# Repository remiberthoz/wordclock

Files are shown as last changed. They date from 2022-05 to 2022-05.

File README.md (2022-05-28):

# Wordclock

This repository contains source code and CAD files to build and program a
wordclock.

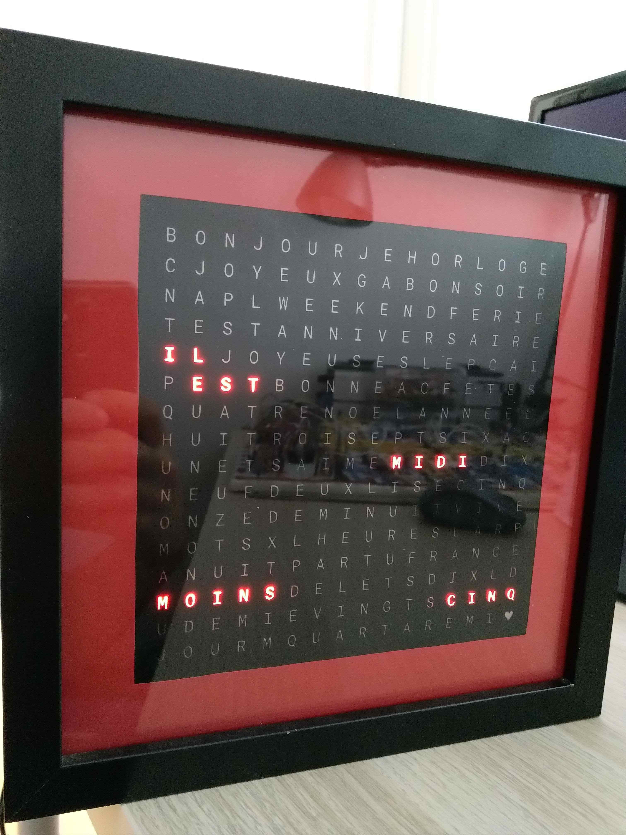
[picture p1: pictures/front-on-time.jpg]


The wordclock is designed inside an IKEA frame (SANNAHED, 25x25 cm). Behind the
front glass panel, a black mask allows light through transparent letters which
are individually backlighted with colour LEDs.

The clock displayed in the picture above spells out the time in French
(*il est midi moins cinq: it is five to noon*), but
design can easily be adapted to other languages. In addition to time of the day,
extra text for special days (*i.e.* birthdays) is highlighted in other colours.
Letters can be used as pixels to display other forms of text. The picture below
displays today's date (*Lun 18 04*: Monday *Lundi* the 18th of April).

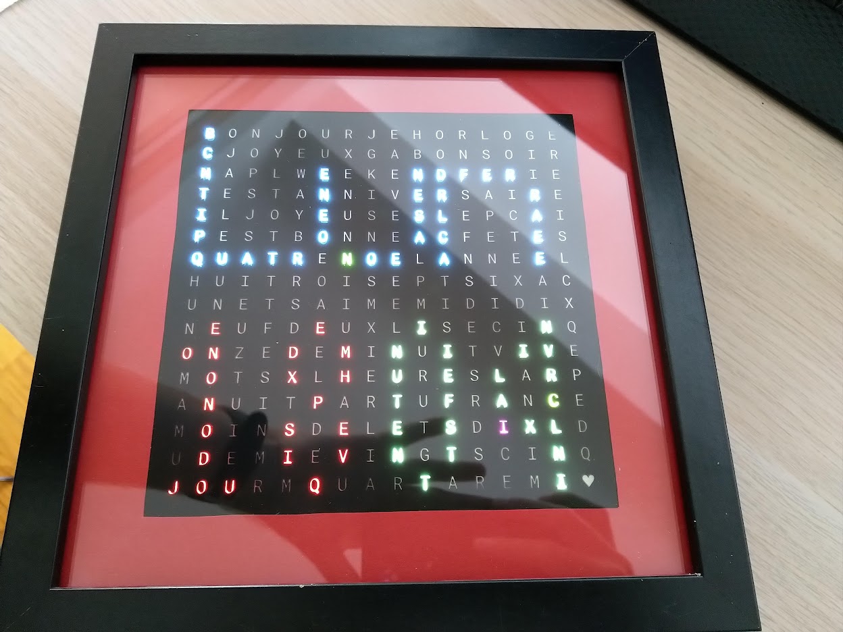
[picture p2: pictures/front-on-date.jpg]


Lights are controlled via custom printed circuit boards, multichannel LED driver
integrated circuits, and an Arduino Nano Every board breaking out a AVR XMEGA
4809 microcontroller. Timekeeping is performed with an accurate Real Time Clock
(RTC, DS3231M). The clock is powered via 5V/4A on a barrel jack, and the RTC is
internaly powered from a coin cell to ensure timekeeping even when the clock is
unplugged.

The source code attempts to follow SOLID principles. It should be easy to update
by anyone willing to add features, modify the word layout, alter colours, add
animations, and so on. As examples, the git repository includes extra behaviours
for the clock:

- it can display time with numbers, using letters as pixels
  ([source](src/Behaviour/TimeInNumbers/)),
- similarly, it can display the date ([source](src/Behaviour/DateInNumbers/)),
- on startup, it shows a splash screen with a welcome message
  ([source](src/Behaviour/HelloMessage/)),
- to debug electrical connecticity and software mappings, LEDs can be controlled
to blink one at a time ([source](src/Behaviour/BlinkOneAtATime/)),

All behaviours can be loaded on the clock, one can then use physical buttons at
the back of the frame to switch between behaviours. These buttons also permit to
adjust the time and date.

# LICENSE

Unless otherwise mentioned, the source code is licensed by Rémi Berthoz under
the [MIT License](LICENSE.txt). Exceptions are:

- The OneButton library (in `src/Protocols/OneButtons`) used to control the
  hardware push-buttons, which is licensed by Matthias Hertel under a BSD style
  license (http://www.mathertel.de/License.aspx).

- The USB USART library (in `src/Protocols/USB_USART`), adapted from
  [ArduinoCore-megaavr](https://github.com/arduino/ArduinoCore-megaavr), which
  is licensed by Arduino SA. under the terms of the GNU Lesser General Public
  License.

- The `src/millis.cpp` file, adapted from
  [ArduinoCore-megaavr](https://github.com/arduino/ArduinoCore-megaavr), which
  is licensed by Arduino SA. under the terms of the GNU Lesser General Public
  License.

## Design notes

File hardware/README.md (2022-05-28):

# KiCAD files for the project.

Contains both PCBs and mounting parts. PCBs ordered from JLCPCB, mounting parts
laser-cut ordered from Sculpteo.

* `led-matrix-pcbs` (pictures: [front with LEDs](../pictures/pcb-led-matrix-front-leds-soldered.jpg), [front without LEDs](../pictures/pcb-led-matrix-front.jpg), [back](../pictures/pcb-led-matrix-back.jpg)):
  * Main PCB, hosting the LEDs and the LED drivers. Each PCB contains 12 RGB
  LEDs in a 3x4 grid (36 LEDs total).
  * With 24 PCBs aranged in a 6x4 grid, one can get a 16x16 grid of RGB LEDs.
  * Each LED on a PCB is controlled via the onboard driver. The driver is
  controlled by a I2C interface, for which pinout is available on the PCB. The
  I2C address of the driver can be adjusted via the ADR pin (see driver
  datasheet).
* `led-matrix-bridge-pcbs` ([picture](../pictures/pcb-bridge-back.jpg)):
  * Connector PCB to join the `led-matrix-pcbs`. Each connector PCB can connect
  4 `led-matrix-pcbs` on a row.
  * This highly simplifies the I2C connections, the ADR configuration, and
  power delivery.
  * Connection between `led-matrix-pcbs` and `led-matrix-bridge-pcbs` is easy
  with pin headers.
  * With 6 PCBs, one can connect 6 rows of 4 `led-matrix-pcbs` to reach 256 RGD
  LEDs.
  * `led-matrix-bridge-pcbs` are easily connected to each other for power
  and for the SCL line of the I2C protocol. Pinout is available for the SDA line
  of the I2C protocol.
* `spacers-laser-cut`:
  * Design for laser-cut plates that hold the PCBs while letting the light of
  the LEDs through.

The main controller (that gives instructions to the LED drivers) is an Arduino
Nano Every. Timekeeping is performed by a DS3231M (breakout board from DFRobot).

## Bill of Materials

### Mounting parts

Laser-cut plates (Scultpeo):
  * 1x backplate-decor, MDF 3mm
  * 1x spacer-mount-leds, Ondulated cardboard 2.8mm
  * 1x spacer-mount-leds, Standard MDF 3mm
  * 2x spacer-nomount-leds-solderjoints, Grey compact cardboard 1mm

Screws (vis-express):
  * Screw M1.6X16 inox
  * Bolt M1.6 inox
  * Washer M2 nylon

### PCBs

PCBs (JLCPCB):
  * 24x led-matrix-pcbs, FR4 1.6mm

  | Matrix front (with LEDs) | Matrix front (without LEDs) | Matrix back |
  |:-----------------:|:--------------------:|:----:|
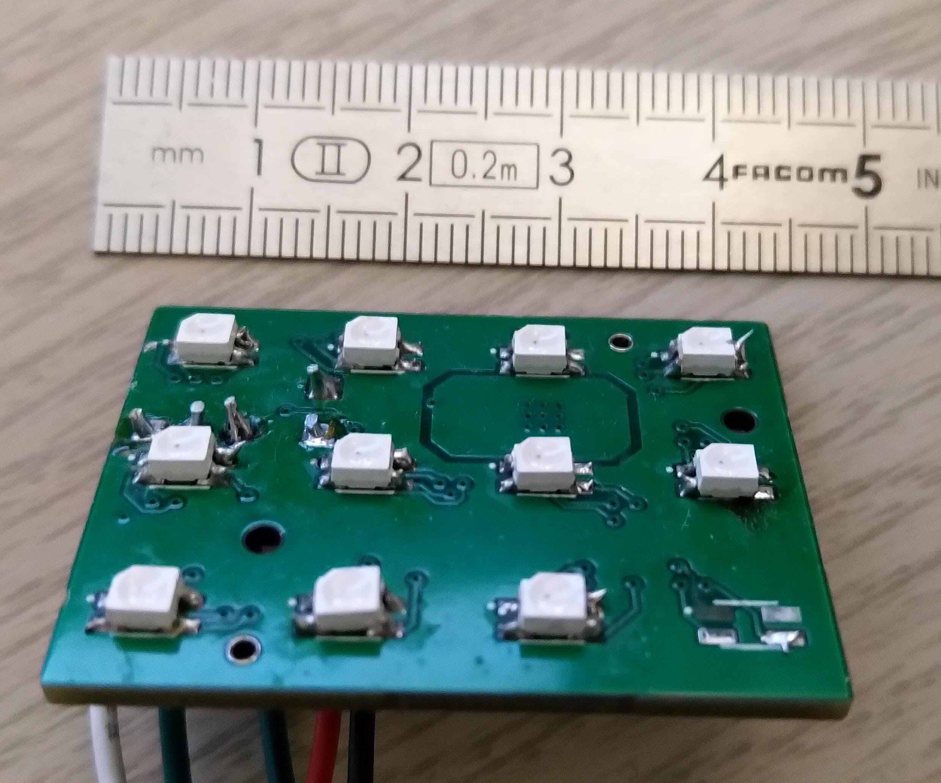
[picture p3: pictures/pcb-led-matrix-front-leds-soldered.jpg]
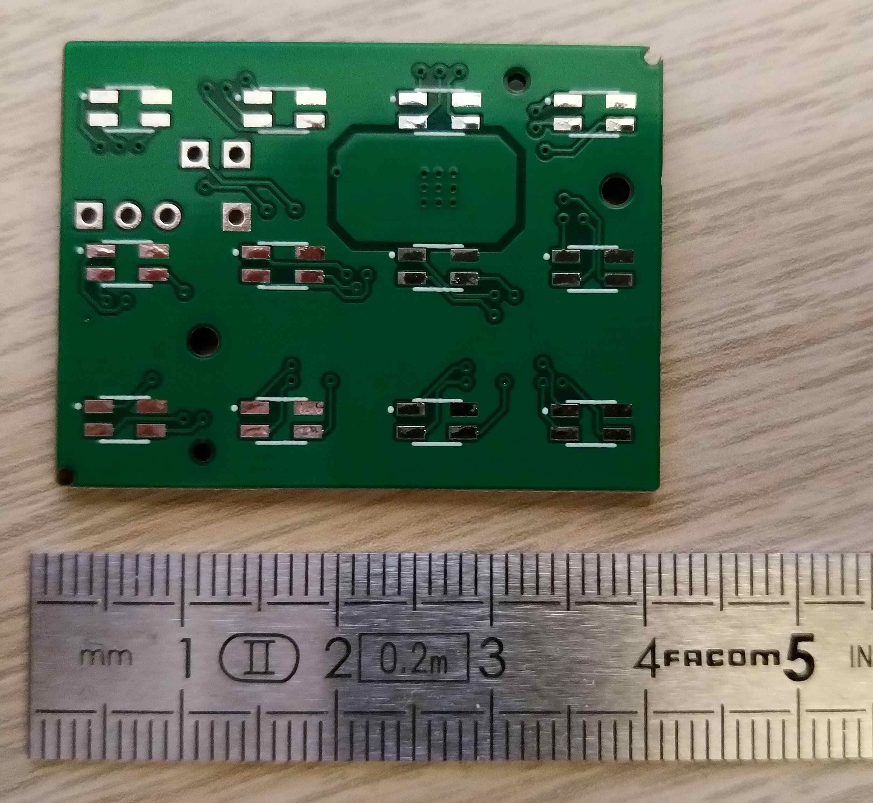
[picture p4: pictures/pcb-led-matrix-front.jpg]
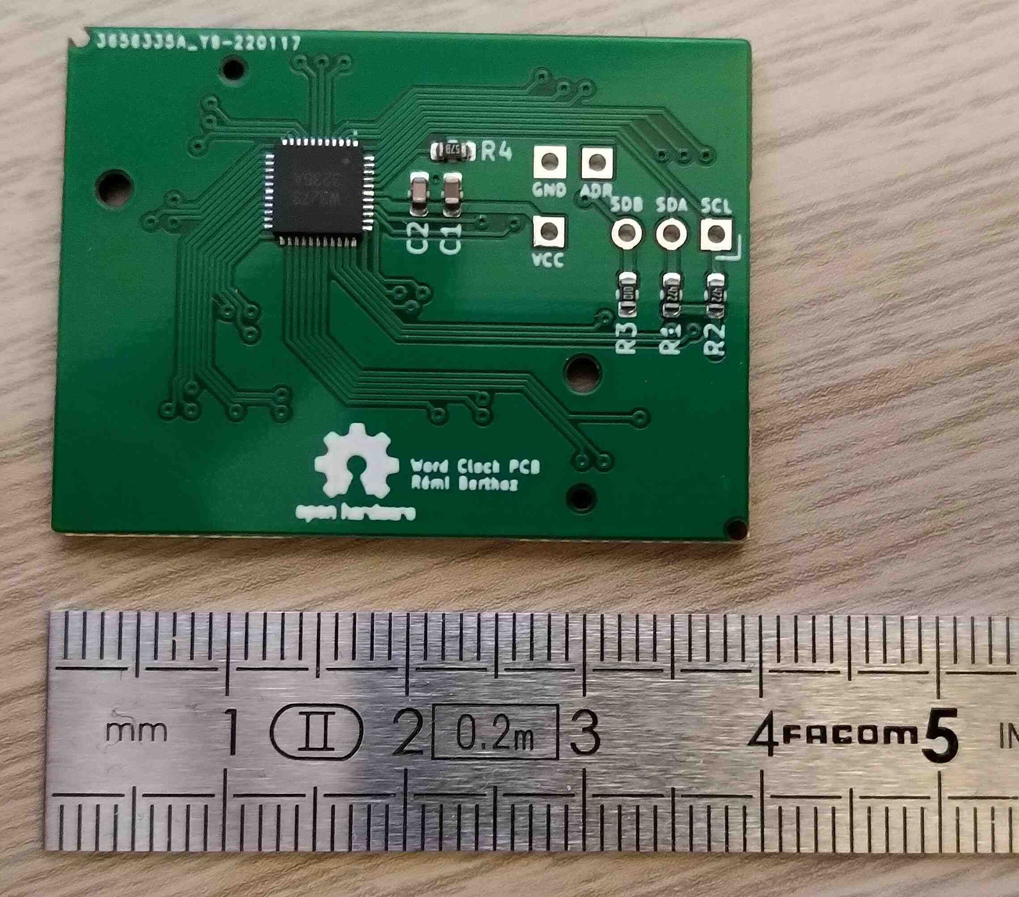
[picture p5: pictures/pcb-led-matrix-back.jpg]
  |  |  |  |

  * 6x led-matrix-bridge-pcbs, FR4 1.6mm

  | Bridge, connects 4 `led-matrix-pcbs` together |
  |:------:|
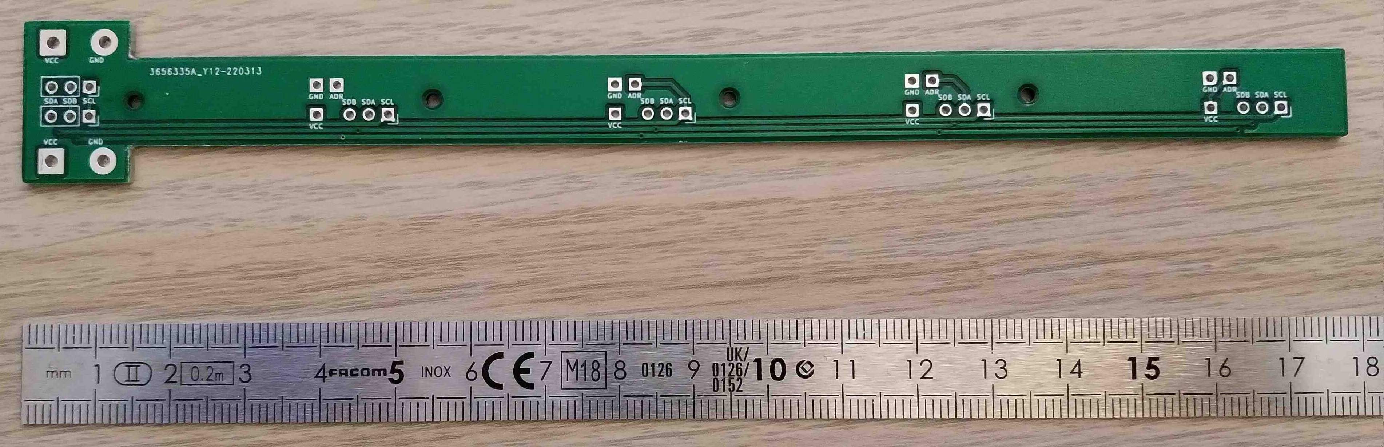
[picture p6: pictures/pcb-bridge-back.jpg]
  |  |

Electronic components (ordered from Mouser and hand-solder, or assembled by JLCPCB):

Count | Part description    | Manufacturer reference | Manufacturer | Odered from
------|---------------------|----------------|--------------|---------------------------
256 | RGB LED               | IN-P32TATRGB   | Inolux   | Mouser
24  | 36 channel LED driver | IS31FL3236A    | Integrated Silicon Solution | JLCPCB (C246443)
24  | 100 kOhm              | 0603WAF1003T5E | Uniroyal | JLCPCB (C25803)
24  | 3.83 kOhm             | 0603WAF3831T5E | Uniroyal | JLCPCB (C22982)
24  | 4.7 kOhm              | 0603WAJ0472T5E | Uniroyal | JLCPCB (C25999)
48  | 100 nF                | CC0603KRX7R9BB104 | Yageo | JLCPCB (C14663)
24  | 1 uF                  | CL10A105KB8NNNC | Samsung Electro-Mechanics | JLCPCB (C15849)

## Stack layers of PCB, mounting, components:

```
..........................................................  glass window
------------------          ------------------------------  paper with letter matrix cutout
~~~~~~\    /~~~~~~          ~~~~~~~~~~~~~~~~~~~~~~~~~~~~~~  ondulated cardboard (spacer-mount-leds)
       \__/                                                 16mm screw
XXXXXXXX||XXXXXXXX          XXXXXXXXXXXXXXXXXXXXXXXXXXXXXX  MDF (spacer-mount-leds)
XXXXXXXX||XXXXXXXX          XXXXXXXXXXXXXXXXXXXXXXXXXXXXXX
XXXXXXXX||XXXXXXXX \light / XXXXXXXXXXXXXXXXXXXXXXXXXXXXXX
::::::::||:::::     \cone/     ::::::::::    :::::::::::::  Compact cardboard  (spacer-nomount-leds-solderjoints)
::::::::||::::: __==========__ :::::::::: /\ :::::::::::::  Compact cardboard  (spacer-nomount-leds-solderjoints)
        ||    _/     LED      \_        _/  \_              Solder joints and LEDs
========||===============================|  |=============  PCB (led-matrix-pcbs)
========||===============================|  |=============
        ||                               |  |               Connector pin
        ||                               |  |
        ||                               |  |
========||===============================|  |=============  PCB (led-matrix-bridge-pcbs)
========||===============================|  |=============
      --||--                             \  /               Solder joints, screw washer
      BB||BB                              \/                Screw bold
        ||
```

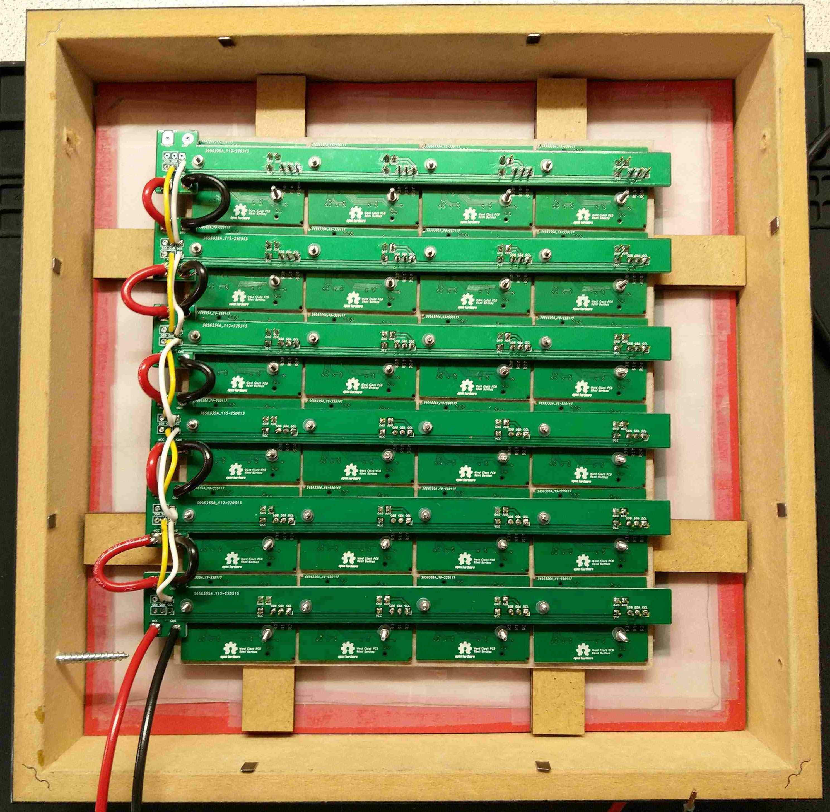
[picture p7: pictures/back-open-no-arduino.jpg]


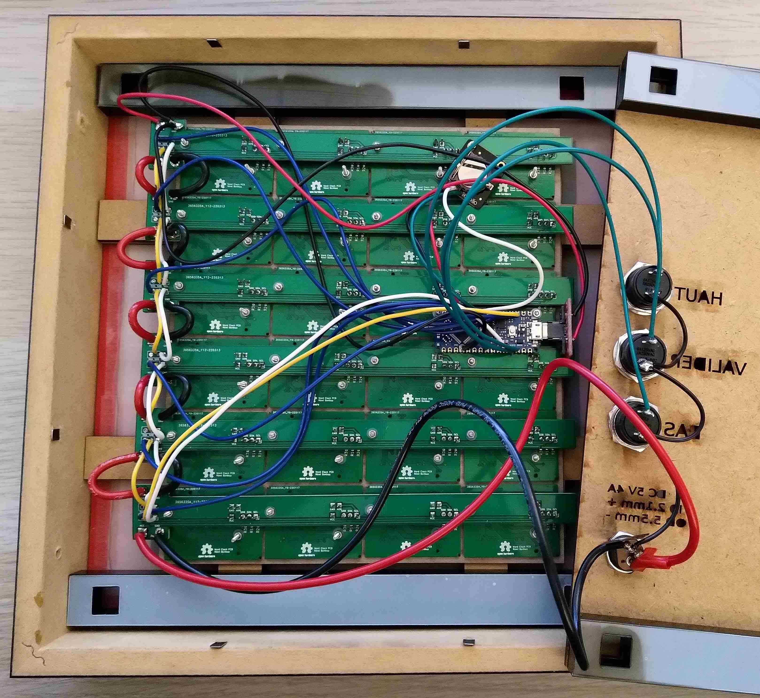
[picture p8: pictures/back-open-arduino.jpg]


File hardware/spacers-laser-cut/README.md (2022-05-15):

Designed in KiCad, should be exported to SVG for Sculpteo or other laser cutting
services.

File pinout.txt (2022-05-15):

Circuit pwr check-  E2    USB    E1
                    3.3v         E0
Circuit BUS SDB  -  D7           B1  - Button ENTER
Circuit BUS SDA3 -  D3           B0  - Button DOWN
Circuit BUS SDA2 -  D2           E3  - Circuit BUS SCL
Circuit BUS SDA1 -  D1           A1
Circuit BUS SDA0 -  D0           F4
Peripherals SDA  -  SDA/A2       B2  - Button UP
Peripherals SCL  -  SCL/A3       C6
Circuit BUS SDA4 -  D4           F5
Circuit BUS SDA5 -  D5           A0
                    5V           GND
                    RST          RST
                    GND          RX/C5
                    VIN          TX/C4

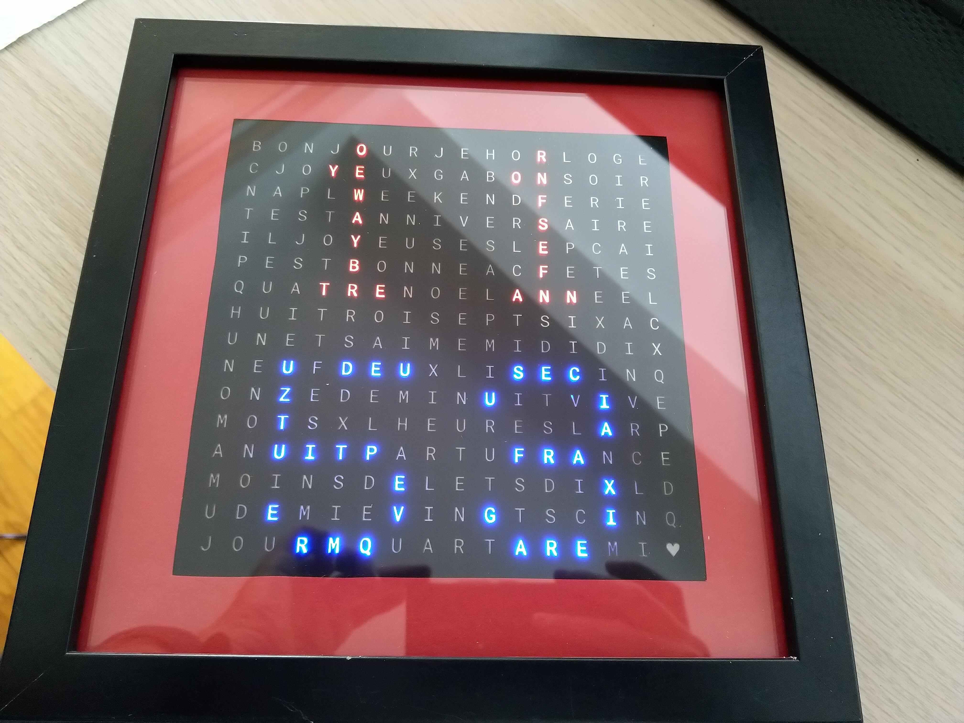
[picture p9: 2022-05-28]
pictures/front-on-time-with-numbers.jpg

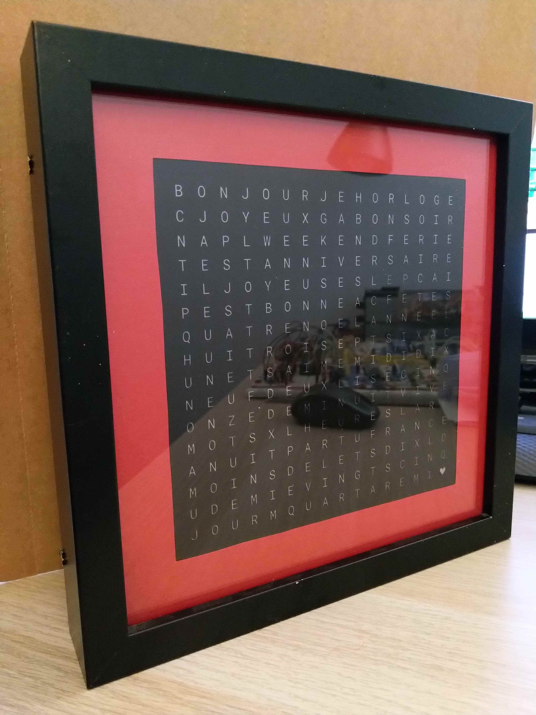
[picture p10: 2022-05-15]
pictures/front-off.jpg

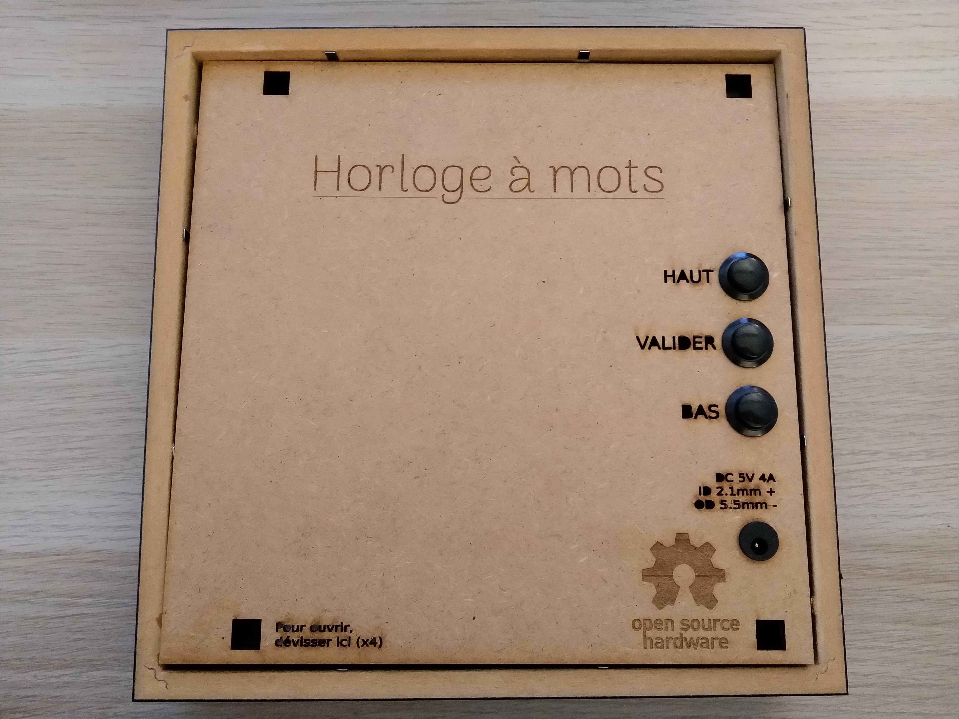
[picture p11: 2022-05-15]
pictures/back-closed.jpg

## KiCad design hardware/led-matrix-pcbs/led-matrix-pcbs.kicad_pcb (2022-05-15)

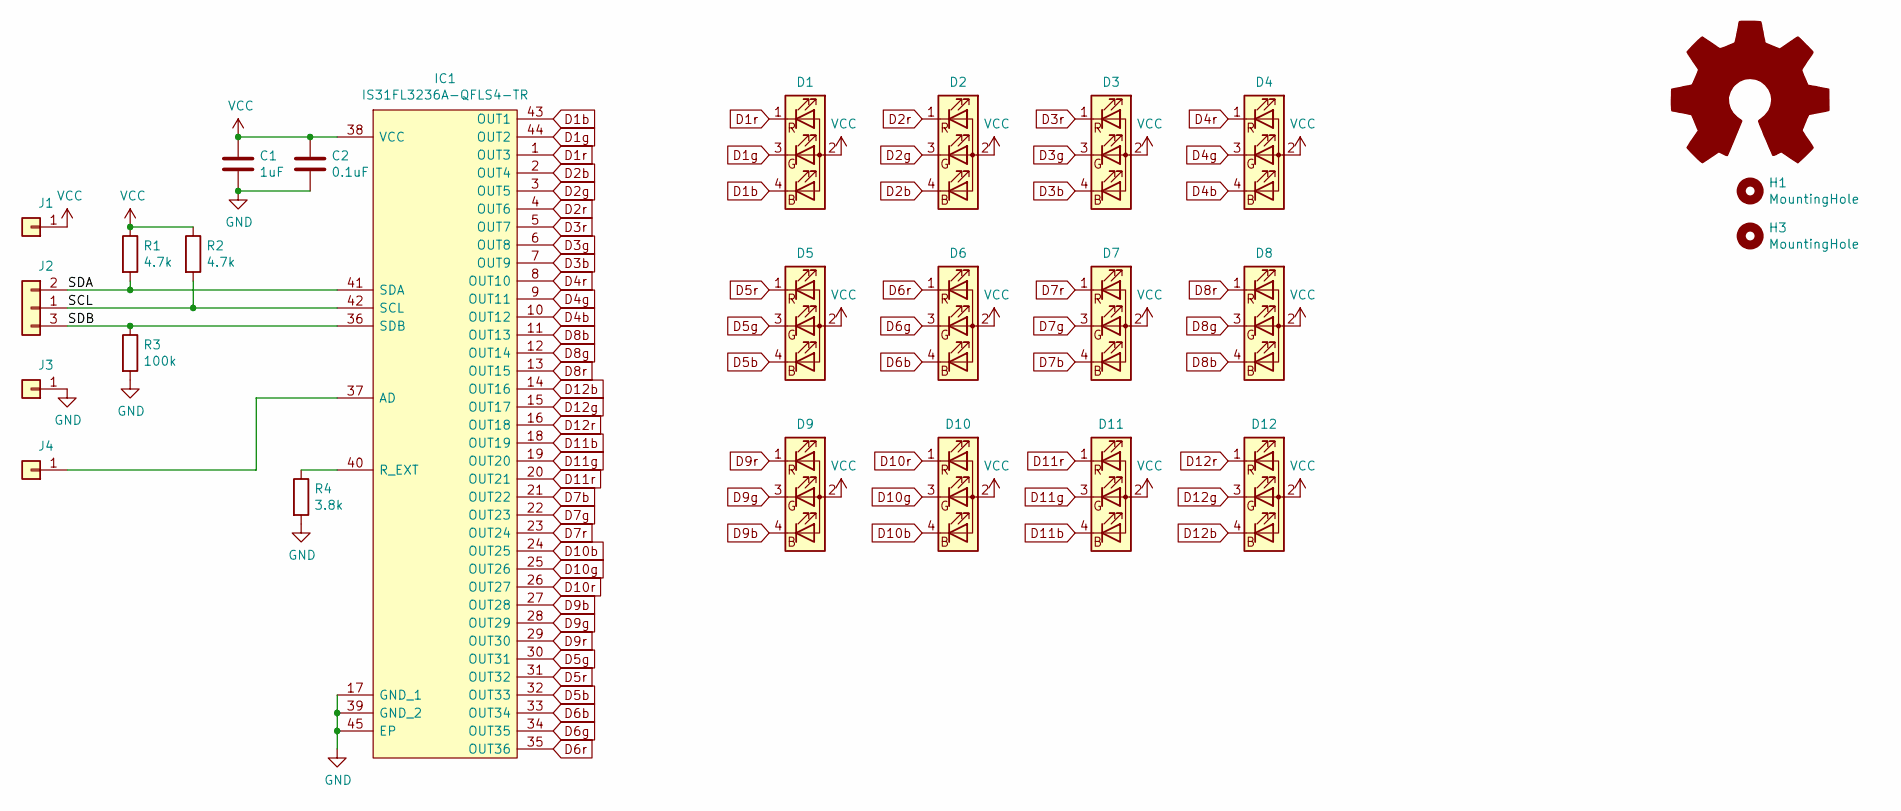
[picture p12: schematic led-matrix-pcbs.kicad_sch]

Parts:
C1: 1uF; C_0603_1608Metric; MouserNo 187-CL10B105KA8NNNC
C2: 0.1uF; C_0603_1608Metric; MouserNo 187-CL10B103KB8NNNC
D1, D2, D3, D4, D5, D6, D7, D8, D9, D10, D11, D12: LED_RAGB; INP32TATRGB; MouserNo 743-IN-P32TATRGB
H1, H3: MountingHole; #2-56; MouserNo na
IC1: IS31FL3236A-QFLS4-TR; IS31FL3236AQFLS4TR; Manufacturer_Part_Number IS31FL3236A-QFLS4-TR; MouserNo 870-IS31FL3236ATQLS4
J1, J3, J4: Conn_01x01; PinHeader_1x01_P2.54mm_Vertical; MouserNo na
J2: 01x03_312; PinSocket_1x03_P2.54mm_Vertical; MouserNo na
LOGO1: Logo_Open_Hardware_Large; OSHW-Logo2_7.3x6mm_SilkScreen; MouserNo na
R1, R2: 4.7k; R_0603_1608Metric; MouserNo 755-ESR03EZPJ472
R3: 100k; R_0603_1608Metric; MouserNo 755-ESR03EZPJ104
R4: 3.8k; R_0603_1608Metric; MouserNo 755-ESR03EZPJ392

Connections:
/SCL: IC1.42 (SCL), J2.1, R2.2
/SDA: IC1.41 (SDA), J2.2, R1.2
/SDB: IC1.36 (SDB), J2.3, R3.1
D1b: D1.4 (BK), IC1.43 (OUT1)
D1g: D1.3 (GK), IC1.44 (OUT2)
D1r: D1.1 (RK), IC1.1 (OUT3)
D2b: D2.4 (BK), IC1.2 (OUT4)
D2g: D2.3 (GK), IC1.3 (OUT5)
D2r: D2.1 (RK), IC1.4 (OUT6)
D3b: D3.4 (BK), IC1.7 (OUT9)
D3g: D3.3 (GK), IC1.6 (OUT8)
D3r: D3.1 (RK), IC1.5 (OUT7)
D4b: D4.4 (BK), IC1.10 (OUT12)
D4g: D4.3 (GK), IC1.9 (OUT11)
D4r: D4.1 (RK), IC1.8 (OUT10)
D5b: D5.4 (BK), IC1.32 (OUT33)
D5g: D5.3 (GK), IC1.30 (OUT31)
D5r: D5.1 (RK), IC1.31 (OUT32)
D6b: D6.4 (BK), IC1.33 (OUT34)
D6g: D6.3 (GK), IC1.34 (OUT35)
D6r: D6.1 (RK), IC1.35 (OUT36)
D7b: D7.4 (BK), IC1.21 (OUT22)
D7g: D7.3 (GK), IC1.22 (OUT23)
D7r: D7.1 (RK), IC1.23 (OUT24)
D8b: D8.4 (BK), IC1.11 (OUT13)
D8g: D8.3 (GK), IC1.12 (OUT14)
D8r: D8.1 (RK), IC1.13 (OUT15)
D9b: D9.4 (BK), IC1.27 (OUT28)
D9g: D9.3 (GK), IC1.28 (OUT29)
D9r: D9.1 (RK), IC1.29 (OUT30)
D10b: D10.4 (BK), IC1.24 (OUT25)
D10g: D10.3 (GK), IC1.25 (OUT26)
D10r: D10.1 (RK), IC1.26 (OUT27)
D11b: D11.4 (BK), IC1.18 (OUT19)
D11g: D11.3 (GK), IC1.19 (OUT20)
D11r: D11.1 (RK), IC1.20 (OUT21)
D12b: D12.4 (BK), IC1.14 (OUT16)
D12g: D12.3 (GK), IC1.15 (OUT17)
D12r: D12.1 (RK), IC1.16 (OUT18)
GND: C1.2, C2.2, IC1.17 (GND_1), IC1.39 (GND_2), IC1.45 (EP), J3.1, R3.2, R4.2
unnamed: IC1.37 (AD), J4.1
unnamed: IC1.40 (R_EXT), R4.1
VCC: C1.1, C2.1, D1.2 (A), D2.2 (A), D3.2 (A), D4.2 (A), D5.2 (A), D6.2 (A), D7.2 (A), D8.2 (A), D9.2 (A), D10.2 (A), D11.2 (A), D12.2 (A), IC1.38 (VCC), J1.1, R1.1, R2.1

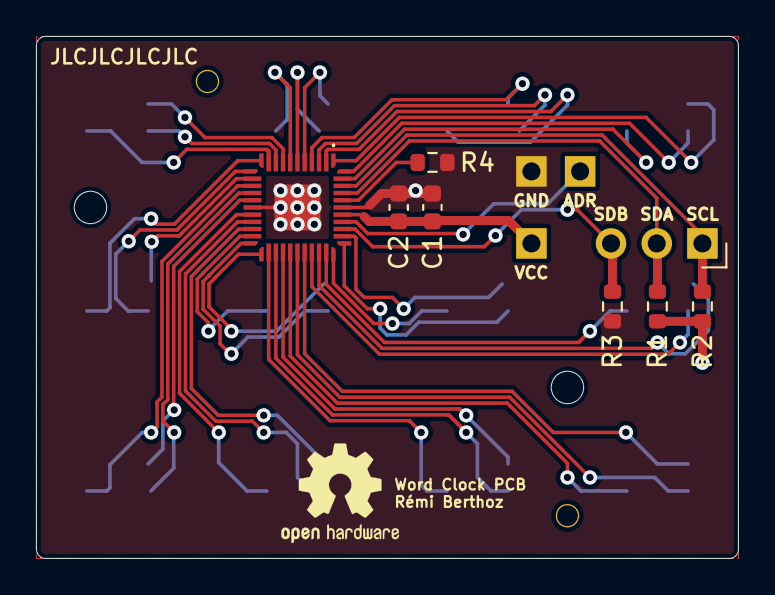
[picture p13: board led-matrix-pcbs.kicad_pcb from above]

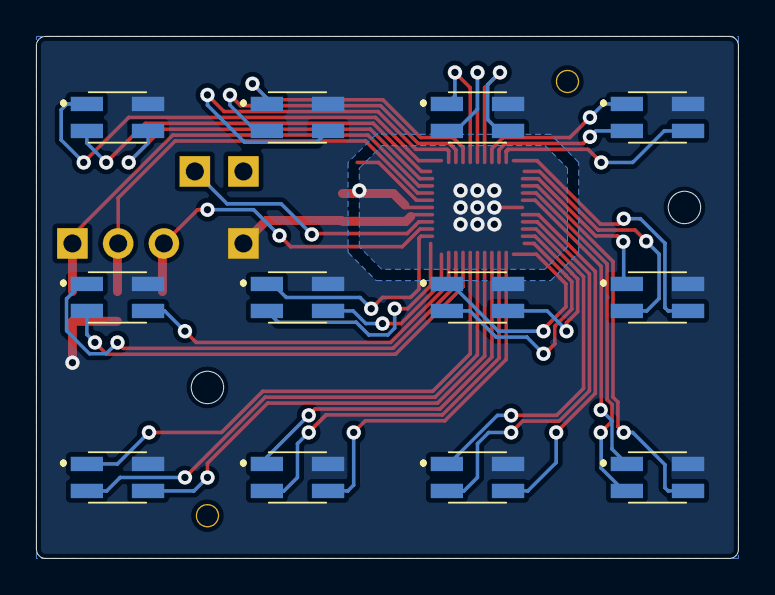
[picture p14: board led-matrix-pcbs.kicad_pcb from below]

Board: 2 copper layers, 39.0 x 29.0 mm, 26 parts (13 on the bottom side), 43 nets.

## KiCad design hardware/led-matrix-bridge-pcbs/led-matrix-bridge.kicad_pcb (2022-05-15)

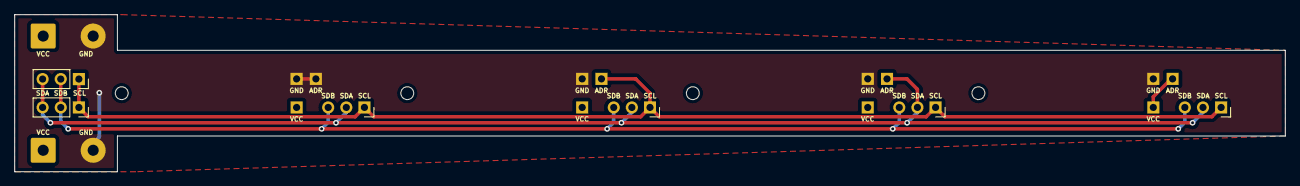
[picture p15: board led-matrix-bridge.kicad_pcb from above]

Board: 2 copper layers, 178.0 x 22.0 mm, 24 parts (0 on the bottom side), 2 nets.

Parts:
H1, H2, H5, H7: MountingHole; #2-56
J1, J3, J4, J5, J7, J8, J9, J11, J12, J13, J15, J16: Conn_01x01; PinHeader_1x01_P2.54mm_Vertical
J2, J6, J10, J14, J18, J20: Conn_01x03; PinSocket_1x03_P2.54mm_Vertical
J17, J19: Conn_01x02; SolderWire-0.75sqmm_1x02_P7mm_D1.25mm_OD3.5mm

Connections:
GND: J3.1, J4.1, J8.1, J12.1, J16.1, J17.2, J19.2
VCC: J1.1, J5.1, J9.1, J13.1, J15.1, J17.1, J19.1

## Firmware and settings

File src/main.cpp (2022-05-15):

#include "Behaviour/behaviourmanager.h"
#include "Display/display.h"
#include "Peripherals/RealTimeClock/rtc.h"
#include "Peripherals/EventKeys/eventkeys.h"
#include "millis.h"
#include "Verbose/verbose.h"
#include "config.h"

#include <avr/interrupt.h>
#include <time.h>
#include <util/delay.h>
#include <util/eu_dst.h>


/**
 * Executes the run() method of a BEHAVIOUR until it returns false or the user quits.
 */
static void exhaust_behaviour(Behaviour*const behaviour) {

    while (1) {

        unsigned long start = millis();

        tm timeinfo = RealTimeClock::fetch_time();
        bool r = behaviour->run(&timeinfo);
        if (!r)
            return;

        EventKeys::Event pending_event{};

        while (millis() - start <= 500) {
            EventKeys::fetch();
            pending_event = EventKeys::get_pending();
            if (pending_event != EventKeys::Event::NONE)
                break;
        }

        switch (pending_event) {

            case EventKeys::Event::NEXT:
                printf_warn("Handling NEXT\n");
                behaviour->next(&timeinfo);
                break;

            case EventKeys::Event::PREV:
                printf_warn("Handling PREV\n");
                behaviour->prev(&timeinfo);
                break;

            case EventKeys::Event::VALIDATE:
                printf_warn("Handling VALIDATE\n");
                behaviour->validate(&timeinfo);
                break;

            case EventKeys::Event::VALIDATE_LONG:
                printf_warn("Handling VALIDATE_LONG (QUIT)\n");
                return;

            default:
                break;
        }
    }
}


void init_arduino_board() {

    // Setup clock control
    #pragma GCC diagnostic push
    #pragma GCC diagnostic ignored "-Wold-style-cast"
    _PROTECTED_WRITE(CLKCTRL_MCLKCTRLB, 0);
    #pragma GCC diagnostic pop

    // Setup USB (for stdio.h in Verbose/verbose.h)
    printf_init();

    // Set TCA0 in SPLIT MODE, we look at the LSB counting down from UINT8_MAX
    // down to zero. Activate the DIV64 prescaler, and the underflow interrupt.
    // This is used by the function millis().
    TCA0.SPLIT.CTRLD = TCA_SPLIT_ENABLE_bm;  // SPLIT MODE
    TCA0.SPLIT.LPER = UINT8_MAX;
    TCA0.SPLIT.CTRLA = TCA_SPLIT_CLKSEL_DIV64_gc | TCA_SPLIT_ENABLE_bm;  // TIMER ENABLE
    TCA0.SPLIT.INTCTRL = TCA_SPLIT_LUNF_bm;

    // PORTMUX.USARTROUTEA |= PORTMUX_USART3_NONE_gc;
}


void init_peripherals() {
    set_dst(eu_dst);  // Set timezone
    EventKeys::init();
    RealTimeClock::init();
    while (!Display::init_display()) {};
}


int main() {

    init_arduino_board();
    init_peripherals();
    printf_info("Done initializing\n");

    printf_info("Exhausting startup behaviour\n");
    exhaust_behaviour(BehaviourManager::get_selected_behaviour());
    BehaviourManager::select_next_behaviour();

    while(1) {
        printf_info("Running selected behaviour: %s\n", BehaviourManager::get_selected_behaviour()->behaviourName);
        exhaust_behaviour(BehaviourManager::get_selected_behaviour());
        BehaviourManager::select_next_behaviour();
    }
}

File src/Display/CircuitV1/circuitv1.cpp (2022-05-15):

#include "../../Protocols/I2C/i2cnx.h"
#include "../../Verbose/verbose.h"
#include "circuitv1.h"


#define eight(x) {x, x, x, x, x, x, x, x}
#define if_nack_return(x) if (!ack) { printf_warn("I2CNX: NACK\n"); return x; }

constexpr uint8_t BASE_3236A_ADDR = 0b01111000;

static constexpr uint8_t ROW_OFFSET = 1;
static constexpr uint8_t ROW_PER_BUS = 3;
static constexpr uint8_t COL_PER_ADR = 4;
static constexpr uint8_t CHN_PER_LED = 3; // RGB: 3 channel per led
static constexpr uint8_t N_BUS = 6;
static constexpr uint8_t N_ADR = 4;
static constexpr uint8_t N_BUS_CIRC = 6;  // TODO: This shoulc be equal to N_BUS, unless debuging/developping
static constexpr uint8_t N_ADR_CIRC = 4;  // TODO: This shoulc be equal to N_BUS, unless debuging/developping
static constexpr uint8_t PINS_PER_SUBBOARD = ROW_PER_BUS * COL_PER_ADR * CHN_PER_LED;

static I2CNX I2C8X_CIRCUITV1{N_BUS_CIRC, &PORTE, 3, &PORTD, 0, 3};

static constexpr uint8_t subboard_pin_map[ROW_PER_BUS][COL_PER_ADR][CHN_PER_LED] = {
    {{10, 11, 12}, { 7,  8,  9}, { 6,  5,  4}, { 3,  2,  1}},
    {{15, 14, 13}, {24, 23, 22}, {36, 35, 34}, {32, 31, 33}},
    {{18, 17, 16}, {21, 20, 19}, {27, 26, 25}, {30, 29, 28}}
};

static uint8_t circuit_buffer[N_ADR][PINS_PER_SUBBOARD][N_BUS];

static inline uint8_t merge_3236a_addr(uint8_t var_addr) {
    return static_cast<uint8_t> ( BASE_3236A_ADDR | (var_addr << 1) );
}

static inline uint8_t board_pin_from_row_col_chn(const uint8_t row, const uint8_t col, const uint8_t chn) {
    uint8_t subboard_row = static_cast<uint8_t> ((row + ROW_OFFSET) % ROW_PER_BUS);
    uint8_t subboard_col = static_cast<uint8_t> (col % COL_PER_ADR);
    return static_cast<uint8_t> (subboard_pin_map[subboard_row][3-subboard_col][chn] - 1);
}


static inline uint8_t board_bus_from_row_col(const uint8_t row, const uint8_t col) {
    int posx = (row + ROW_OFFSET) * Display::N_COLS + col;
    return static_cast<uint8_t> (posx / (Display::N_ROWS * ROW_PER_BUS));  // Valid cast since posx<=271, 271/(16*3)=5<255
}


static inline uint8_t board_adr_from_row_col(const uint8_t row, const uint8_t col) {
    int posy = col * Display::N_ROWS + row;
    return static_cast<uint8_t> (3 - (posy / (Display::N_COLS * COL_PER_ADR)) );  // Valid cast since posy<=255, 255/(16*4)=3<255
}


static inline uint8_t board_led_form_row_col(const uint8_t row, const uint8_t col) {
    // relx,rely are x,y coordinated of a LED on its bus,adr pair
    int8_t relx = static_cast<int8_t> (col - COL_PER_ADR * board_adr_from_row_col(row, col));
    int8_t rely = static_cast<int8_t> ((row + ROW_OFFSET) - ROW_PER_BUS * board_bus_from_row_col(row, col));
    return static_cast<uint8_t> (rely*COL_PER_ADR + relx);  // Valid cast since relx<=3 and rely<=2, rely*4+3=11<255
}


static void clear_circuit_buffer() {
    for (uint8_t adr = 0; adr < N_ADR; adr++) {
        for (uint8_t pin = 0; pin < PINS_PER_SUBBOARD; pin++) {
            for (uint8_t bus = 0; bus < N_BUS; bus++) {
                circuit_buffer[adr][pin][bus] = 0;
            }
        }
    }
}


static void update_circuit_buffer_from_display_buffer(uint8_t display_buffer[Display::N_ROWS][Display::N_COLS][3]) {

    for (uint8_t row = 0; row < Display::N_ROWS; row++) {
        for (uint8_t col = 0; col < Display::N_COLS; col++) {
            uint8_t bus = board_bus_from_row_col(row, col);
            uint8_t adr = board_adr_from_row_col(row, col);
            for (uint8_t chn = 0; chn < CHN_PER_LED; chn++) {
                uint8_t pin = board_pin_from_row_col_chn(row, col, chn);
                circuit_buffer[adr][pin][bus] = display_buffer[row][col][chn];
            }
        }
    }
}


bool Display::CircuitV1::impl_init_display() {

    printf_info("Initializing display for CircuitV1\n");
    PORTD.DIRSET = 0b10000000;  // SDB output
    PORTD.OUTSET = 0b10000000;  // SDB high
    I2C8X_CIRCUITV1.init();

    for (uint8_t adr = 0; adr < N_ADR_CIRC; adr++) {

        bool ack;

        printf_debug("Iterrating boards at address: %u\n", adr);
        ack = I2C8X_CIRCUITV1.start_transmit(merge_3236a_addr(adr), 0x00, false);
        if_nack_return(false);
    }

    for (uint8_t adr = 0; adr < N_ADR_CIRC; adr++) {

        bool ack;

        printf_debug("Writing to SHUTDOWN REGISTER\n");
        uint8_t shutdown_no[8] = eight(1);
        ack = I2C8X_CIRCUITV1.start_transmit(merge_3236a_addr(adr), 0x00, true);
        if_nack_return(false);
        ack = I2C8X_CIRCUITV1.transmit(shutdown_no, false);
        if_nack_return(false);

        printf_debug("Writing to LED_CONTROL REGISTER\n");
        uint8_t led_state_on[8] = eight(0b111);
        ack = I2C8X_CIRCUITV1.start_transmit(merge_3236a_addr(adr), 0x26, true);
        if_nack_return(false);

        for (uint8_t pin = 0; pin < PINS_PER_SUBBOARD-1; pin++) {
            ack = I2C8X_CIRCUITV1.transmit(led_state_on, true);
            if_nack_return(false);
        }
        ack = I2C8X_CIRCUITV1.transmit(led_state_on, false);
        if_nack_return(false);
    }

    return true;
}


void Display::CircuitV1::impl_apply_buffer(uint8_t display_buffer[Display::N_ROWS][Display::N_COLS][3]) {

    printf_info("Applying display buffer on CircuitV1\n");

    clear_circuit_buffer();
    update_circuit_buffer_from_display_buffer(display_buffer);

    for (uint8_t adr = 0; adr < N_ADR_CIRC; adr++) {

        bool ack;

        printf_debug("Writing to PWM_CONTROL REGISTER\n");
        ack = I2C8X_CIRCUITV1.start_transmit(merge_3236a_addr(adr), 0x01, true);
        if_nack_return();

        for (uint8_t pin = 0; pin < PINS_PER_SUBBOARD; pin++) {
            ack = I2C8X_CIRCUITV1.transmit(circuit_buffer[adr][pin], true);
            if_nack_return();
        }

        printf_debug("Writing to PWM_UPDATE REGISTER\n");
        uint8_t pwm_update[8] = eight(0);
        ack = I2C8X_CIRCUITV1.transmit(pwm_update, false);
        if_nack_return();
    }
}
